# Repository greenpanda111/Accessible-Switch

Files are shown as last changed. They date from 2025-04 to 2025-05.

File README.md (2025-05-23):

# Accessible-Switch

<div align="center">
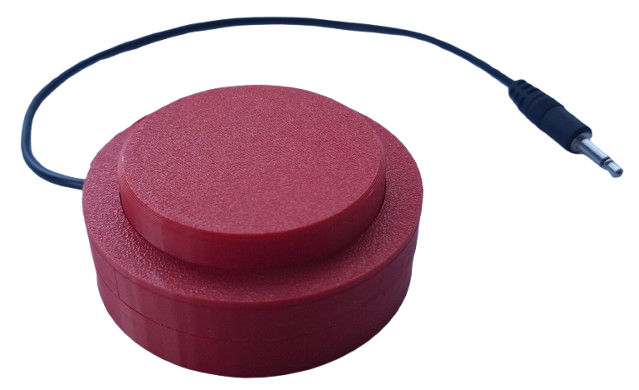
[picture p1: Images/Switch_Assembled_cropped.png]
Switch assembled

</div>

Accessible switches allow people with disabilities to interact with toys, games, or other technologies. They come in many different shapes, sizes, styles, and actuation forces. Each person has their unique switch configuration that best allows them to have maximum freedom. However, these switches can cost as low as £30 for a single, basic switch. This repository aims to improve access to a basic variety of switch for families and charities.

The switch is assembled from three 3D printed parts, a custom PCB, a [microswitch](https://uk.farnell.com/omron-electronic-components/d2fs-f-n/microswitch-plunger-spst-0-1a/dp/2402441), a [3.5mm mono jack cable](https://www.amazon.co.uk/RUNCCI-YUN-3-5mm-soldering-Repairing-Cables/dp/B0CWQN1W4J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), and three springs.

<div align="center">
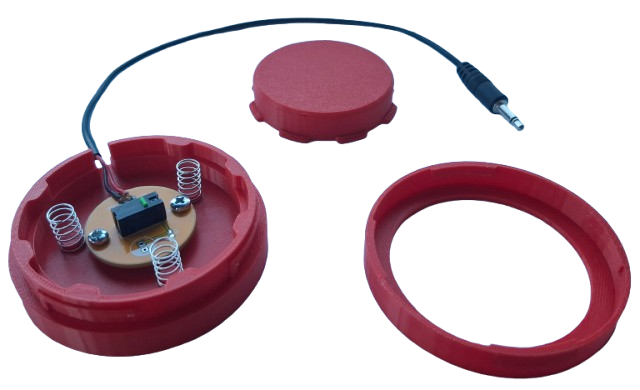
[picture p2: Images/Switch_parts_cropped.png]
Switch parts

</div>

# PCB
PCBs can be ordered through [JLCPCB](https://jlcpcb.com/) with default parameters. Simply download the gerbers.rar file and upload it to JLCPCB. The PCBs only require three pins soldering for the microswitch, and the two mono jack wires. Polarity of the wires does not matter, but when soldering the microswitch, the plunger should be closest to the white circle on the silkscreen. This should be accomplishable by someone with minimal soldering experience. The PCBs also have debouncing capacitor support, but these are not neccessary. A 100uA capacitor would be suitable, however.

<div align="center">
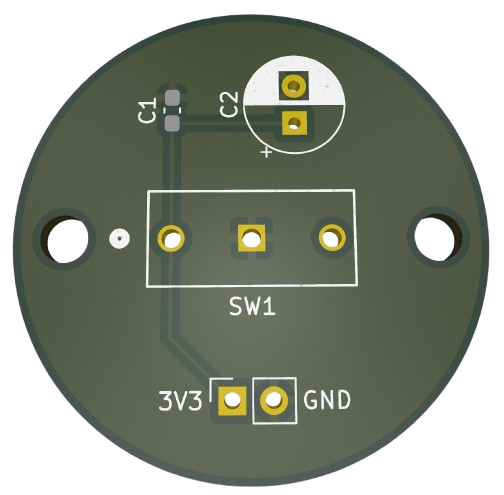
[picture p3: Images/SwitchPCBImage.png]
PCB

</div>

# CAD
Onshape files here: https://cad.onshape.com/documents/298bde2cf99925c17ee02d94/w/1b669208b51cf1bc021c468f/e/d7502f0e0361710259ea8cca 

<div align="center">
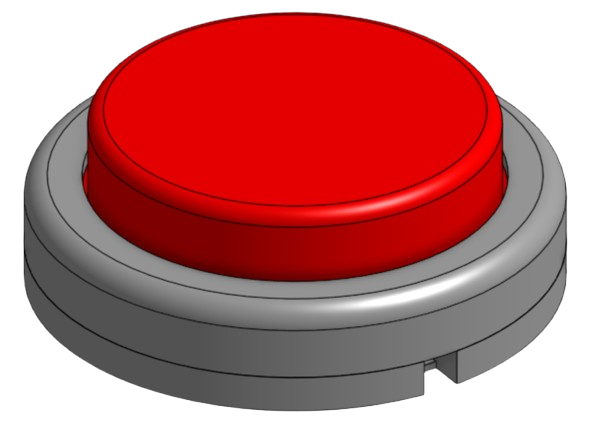
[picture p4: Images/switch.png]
switch CAD

</div>

# Future Improvements:

- Redesign the PCB mounting in the base so that it has a snap-fit connection so screws are not needed. This would allow the base to be even slimmer
- Version 2.0 where there is no locking ring and the plunger can reach the edge of the base

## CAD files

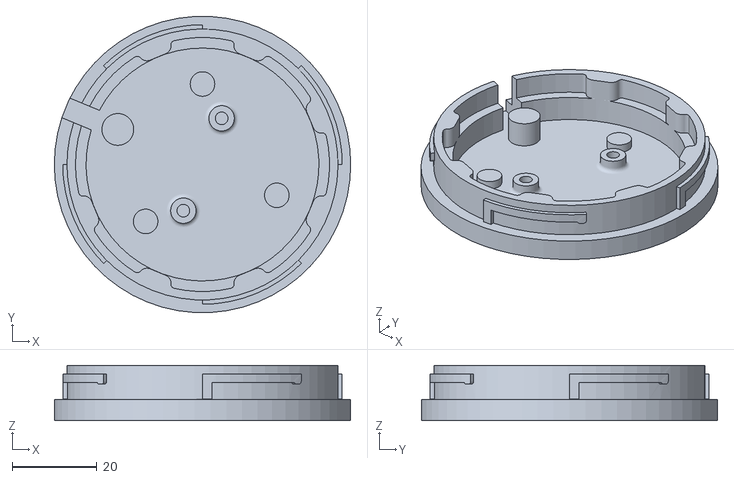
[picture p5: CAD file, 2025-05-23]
3D parts/Bottom Plate.stl
70.0 x 69.9 x 13.0

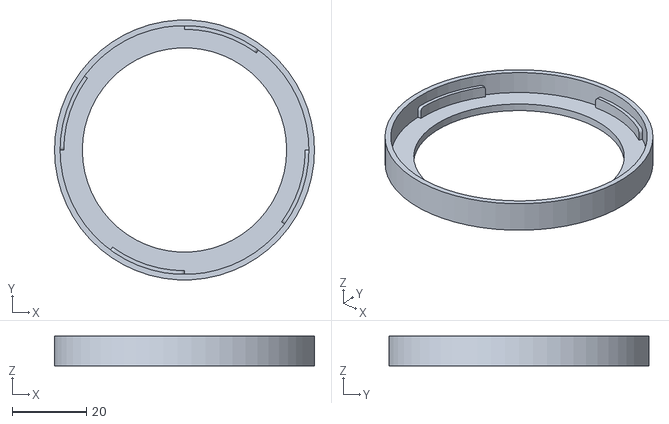
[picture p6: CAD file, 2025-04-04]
top button1.stl
70.0 x 69.9 x 8.00

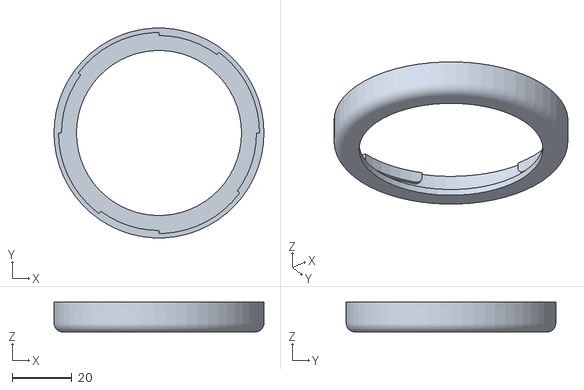
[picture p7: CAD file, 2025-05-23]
3D parts/Locking Ring.stl
70.0 x 69.9 x 10.0

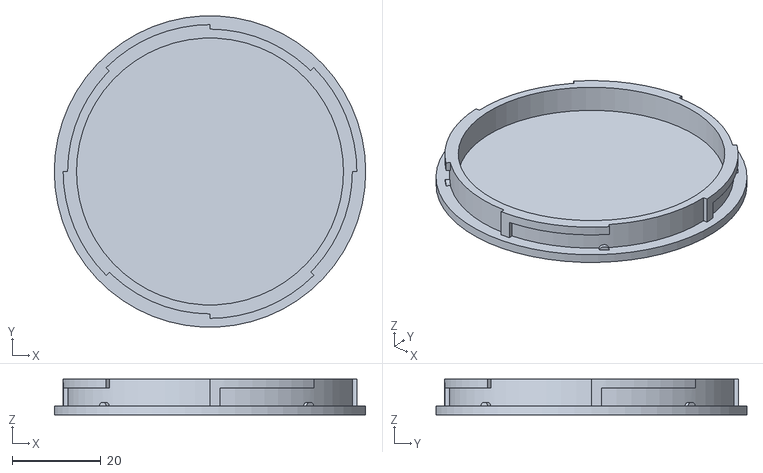
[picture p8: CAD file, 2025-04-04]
Bottom button1.stl
70.0 x 69.9 x 8.00

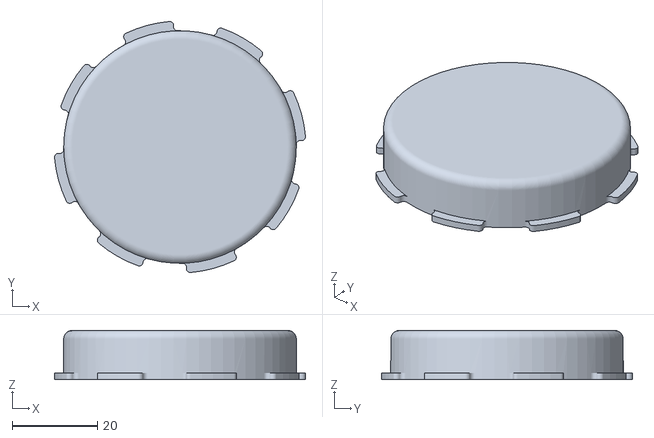
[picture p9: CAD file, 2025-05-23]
3D parts/Plunger.stl
58.8 x 58.8 x 11.5

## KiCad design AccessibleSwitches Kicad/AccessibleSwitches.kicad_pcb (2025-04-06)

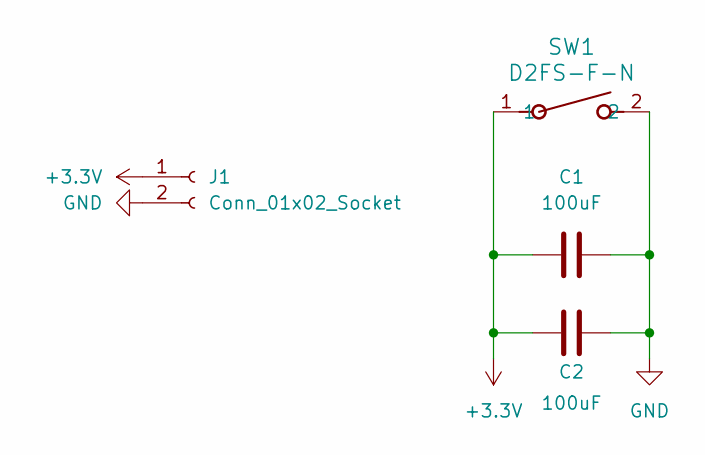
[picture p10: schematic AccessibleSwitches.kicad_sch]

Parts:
C1: 100uF; C_0603_1608Metric_Pad1.08x0.95mm_HandSolder
C2: 100uF; CP_Radial_D6.3mm_P2.50mm
J1: Conn_01x02_Socket; PinSocket_1x02_P2.54mm_Vertical
SW1: D2FS-F-N; SW_D2FS-F-N_OMR

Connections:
+3.3V: C1.1, C2.1, J1.1, SW1.1
GND: C1.2, C2.2, J1.2, SW1.2

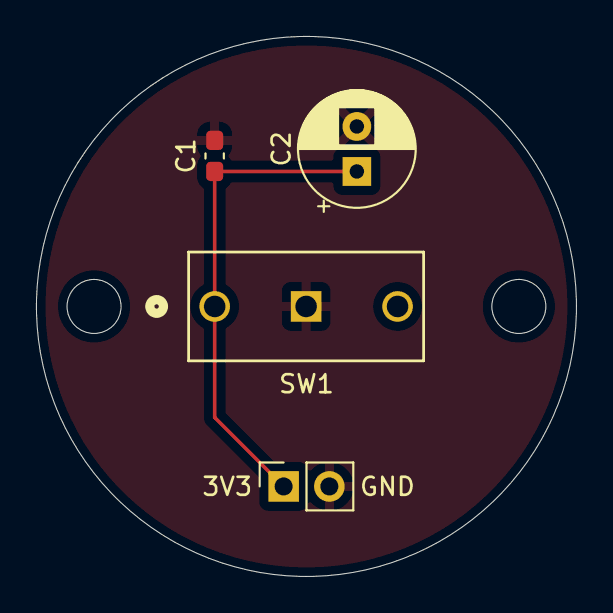
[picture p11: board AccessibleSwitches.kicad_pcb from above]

Board: 2 copper layers, 30.0 x 30.0 mm, 4 parts (0 on the bottom side), 2 nets.

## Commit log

2025-04-04 Current Switch STLs added
    [Bottom button1.stl, top button1.stl]
2025-04-04 PCB Images
    [AccessibleSwitches.kicad_pcb, AccessibleSwitches.kicad_sch]
2025-04-04 CAD Image
2025-04-06 Gerbers added
2025-04-06 git ignore in effect
    [AccessibleSwitches.kicad_pcb, AccessibleSwitches.kicad_sch]
2025-04-06 Kicad files re-added
    [AccessibleSwitches.kicad_pcb, AccessibleSwitches.kicad_sch]
2025-04-06 SMD debouncing cap added
    [AccessibleSwitches.kicad_pcb, AccessibleSwitches.kicad_sch]
2025-04-06 Gerbers and 3D model exported
    [AccessibleSwitches-B_Cu.gbr, AccessibleSwitches-B_Mask.gbr, AccessibleSwitches-B_Paste.gbr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]
2025-04-06 traces cleaned up
2025-04-23 Updated CAD Image
2025-05-23 Smooth and slimmer switches
    [AccessibleSwitches.step, Bottom Plate.stl, Locking Ring.stl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]
